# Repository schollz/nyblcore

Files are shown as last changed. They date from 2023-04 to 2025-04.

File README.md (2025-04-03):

# nyblcore



## diy

- [Website](https://nyblcore.com)
- [Schematic](https://github.com/schollz/nyblcore/blob/main/board/schematic_v1.pdf)
- [Board files](https://github.com/schollz/nyblcore/tree/main/board)
- [Source code](https://github.com/schollz/nyblcore/blob/main/nyblcore/nyblcore.ino)
- [Firmware](https://infinitedigits.co/wares/nyblcore/#upload)
- [Instructions for uploading firmware](https://infinitedigits.co/wares/nyblcore/#uploading-firmware-tools) 
- [Video demonstration](https://www.youtube.com/watch?v=cA8lai6gwKw)
- [Video DIY guide](https://www.youtube.com/watch?v=mrZleTfIKjE)

## what is it?

nyblcore is...

- a tiny **ATtiny85-based sample player** device for diy enthusiasts.
- powered by a single AAA for **~5-8 hours of battery life**.
- holding 8 kB of storage for up to **1.2 seconds of 8-bit audio sampled @ 4.1 kHz**.
- controlled by multi-functional knobs that modulate tempo, volume, distortion.
- probability-based. knobs also control the chaos of **jump, retrig, stutter and stretch** fx.
- able to **load custom firmware / audio** using an [Arduino](https://www.amazon.com/Arduino-A000066-ARDUINO-UNO-R3/dp/B008GRTSV6/?tag=scholl-20&th=1) or an [AVR usb programmer](https://www.amazon.com/whiteeeen-Tiny-AVR-Programmer/dp/B09921SC7Z/?tag=scholl-20&th=1) with [web-based tool](https://www.notion.so/pikocore-desktop-adf8f2e380b94334857e884fe1b85dcd).
- entirely [open-source](https://github.com/schollz/nyblcore), wonderfully hackable.

nyblcore is available for purchase. The assembled version is ready to play, handmade by me. The kit version comes with all the components (battery included!) and instructions on how to solder it together. 

more information at the website: [nyblcore.com](https://nyblcore.com).

## support open-source

nyblcore is open-source, all the code and boards are on my github here. 

If you make this device yourself, please consider [sponsoring me on github](https://github.com/sponsors/schollz) to support my time and effort in this project and to continue to allow me to explore making devices and releasing them as open-source. 

of course, you can also support this work by [buying the device directly from me](https://nyblcore.com/#buy).

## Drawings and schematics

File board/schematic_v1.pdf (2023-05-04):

## ATTiny85

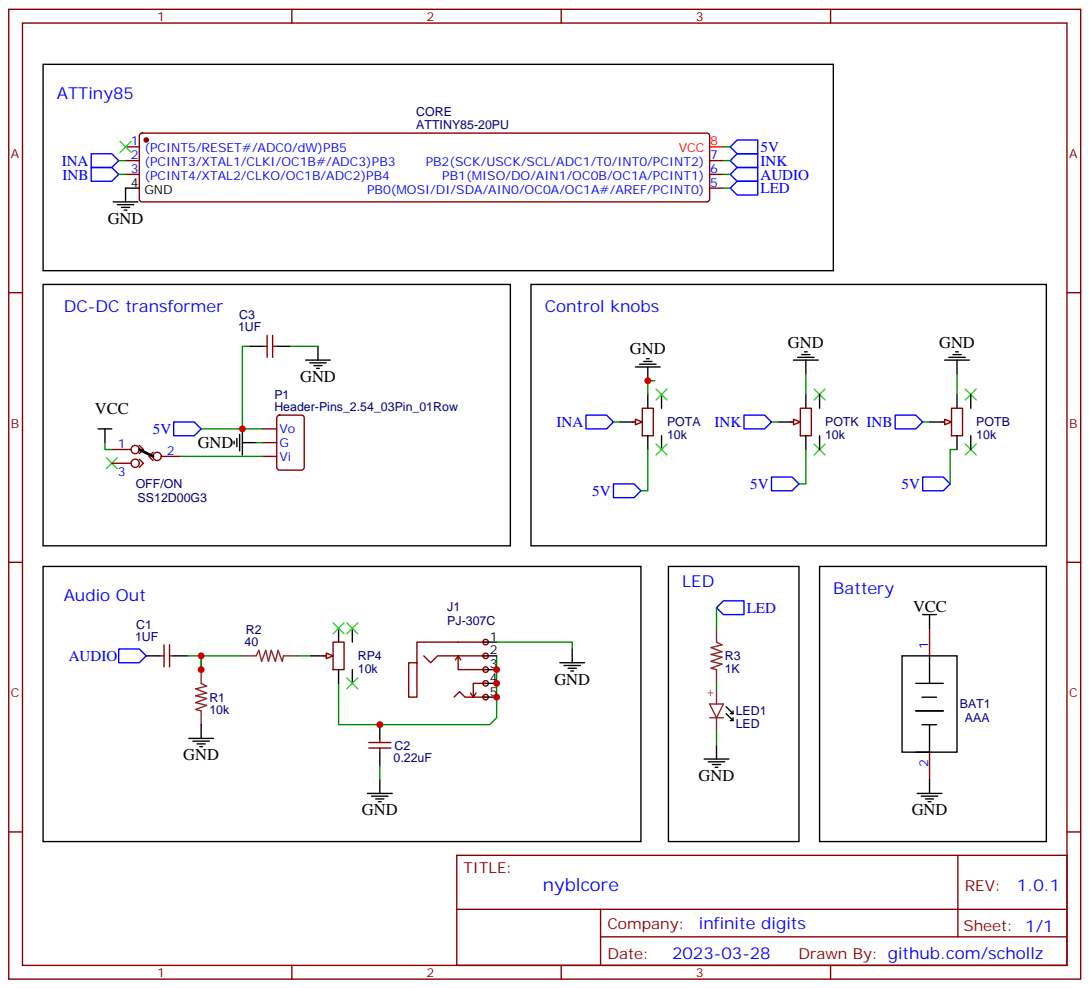
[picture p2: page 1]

PB0(MOSI/DI/SDA/AIN0/OC0A/OC1A#/AREF/PCINT0) 5

Drawn By: github.com/schollz

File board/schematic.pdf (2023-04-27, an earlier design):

## ATTiny85

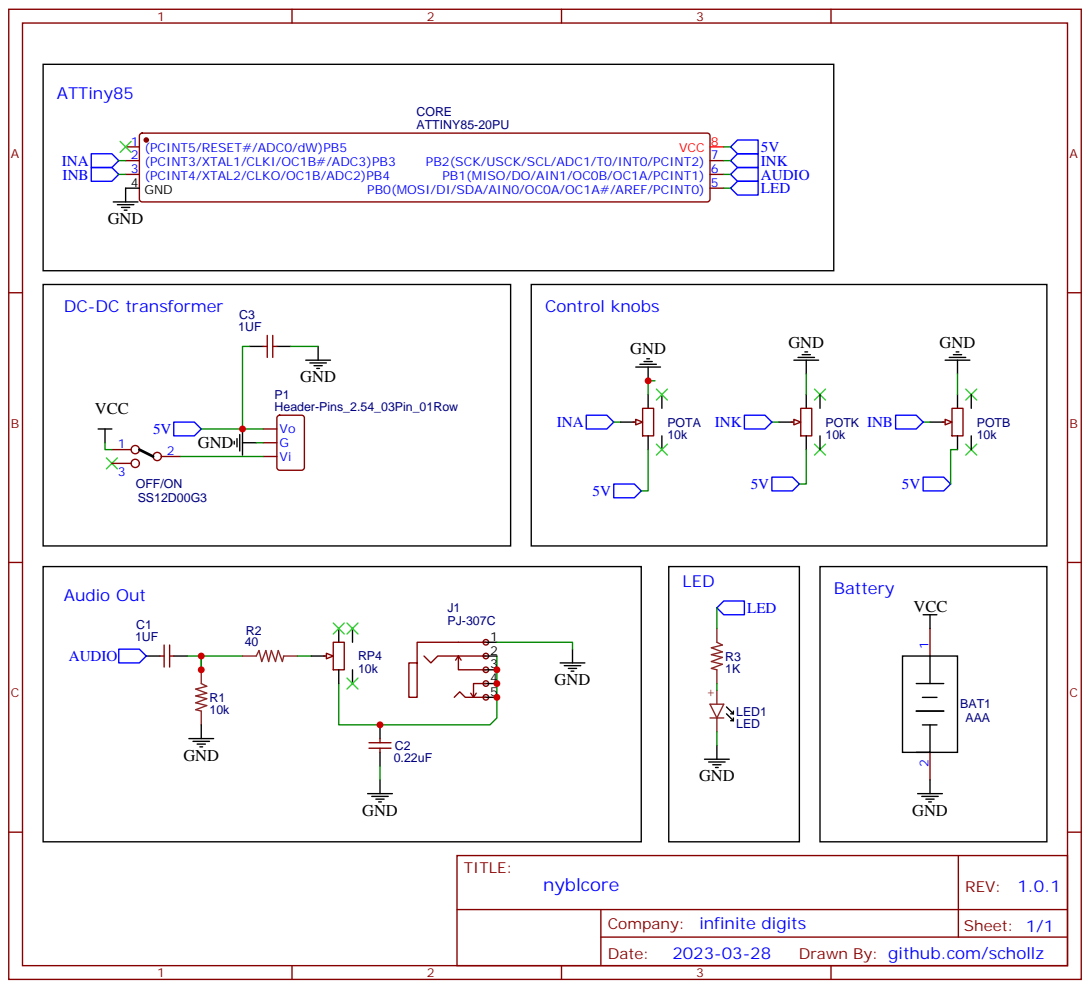
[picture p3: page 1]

PB0(MOSI/DI/SDA/AIN0/OC0A/OC1A#/AREF/PCINT0) 5

Drawn By: github.com/schollz

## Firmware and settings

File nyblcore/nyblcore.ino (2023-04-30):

// nyblcore v1.0.0
//
// ATtiny85 pinout:
//
//         +--u--+
//      NC |1   8| VCC
//     InA |2   7| InK
//     InB |3   6| Audio out
//     GND |4   5| LED out
//         +-----+
//

// <sample>
// SAMPLETABLE
// </sample>

#include <avr/eeprom.h>

// THE FOLLOWING 308 LINES OF CODE FOLLOWS THE MIT LICENSE
//
// MIT License
//
// Copyright (c) 2019 Strick Yak
//
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
#ifndef WHICH_PWM
#define WHICH_PWM 1 /* 1 or 4 */
#endif

#ifndef WHICH_LED
#define WHICH_LED 0
#endif

extern void Setup(void);
extern void Loop(void);

namespace nyblcore_internal {

// Timer/Counter 1 PWM Output OC1A (PB1)
struct FastPwm1Base {
  static void SetupPLL() {
    // de https://github.com/viking/attiny85-player //
    PLLCSR |= _BV(PLLE);  // Enable 64 MHz PLL (p94)
    // SpinDelay(1);         /// delayMicroseconds(100);            // Stabilize
    byte spin_tmp = 0;
    for (byte j = 0; j < 100; j++) {
      spin_tmp++;
    }
    while (!(PLLCSR & _BV(PLOCK)))
      ;                   // Wait for it... (p94)
    PLLCSR |= _BV(PCKE);  // Timer1 source = PLL
  };
};
struct FastPwm1A : public FastPwm1Base {
  static void Setup() {
    SetupPLL();

    // Set up Timer/Counter1 for PWM output
    TIMSK = 0;             // Timer interrupts OFF (p92)
    TCCR1 = _BV(PWM1A)     // Pulse Width Modulator A Enable. (p89)
            | _BV(COM1A1)  // Clear OC1A on match; set on count $00.
            | _BV(CS10);   // 1:1 prescale (p89)
    GTCCR = 0;             // Do not enable PW Modulater B. (p90)
    OCR1C = 255;           // Full 8-bit PWM cycle (p92)
    OCR1B = 0;             // Not used.
    OCR1A = 128;           // 50% duty at start

    pinMode(1, OUTPUT);  // Enable PWM output OC1A on pin PB1.
  }
  static void Output(int x) {
    OCR1A = x;  // (p92)
  }
};

struct FastPwm1B : public FastPwm1Base {
  static void Setup() {
    SetupPLL();

    // Set up Timer/Counter1 for PWM output
    TIMSK = 0;              // Timer interrupts OFF (p92)
    GTCCR = _BV(PWM1B)      // Pulse Width Modulator B Enable. (p89)
            | _BV(COM1B1);  // Clear OC1B on match; set on count $00 (p86).
    TCCR1 = _BV(CS10);      // Do not enable PW Modulater A. 1:1 prescale. (p89)
    OCR1C = 255;            // Full 8-bit PWM cycle (p92)
    OCR1A = 128;            // Not used.
    OCR1B = 128;            // 50% duty at start

    pinMode(4, OUTPUT);  // Enable PWM output OC1B on pin PB4.
  }
  static void Output(int x) {
    OCR1B = x;  // (p92)
  }
};

struct AnalogIn {
  static void NextInputA() {
    ADMUX = 0 |           // Use Vcc for Reference; disconnect from PB0 (p134)
            _BV(ADLAR) |  // Left-Adjust the ADC Result in ADCH (p134)
            3;            // ADC3 is PB3 is A.
  }
  static void NextInputB() {
    ADMUX = 0 |           // Use Vcc for Reference; disconnect from PB0 (p134)
            _BV(ADLAR) |  // Left-Adjust the ADC Result in ADCH (p134)
            2;            // ADC2 is PB4 is B.
  }
  static void NextInputK() {
    ADMUX = 0 |           // Use Vcc for Reference; disconnect from PB0 (p134)
            _BV(ADLAR) |  // Left-Adjust the ADC Result in ADCH (p134)
            1;            // ADC1 is PB2 is K.
  }
  static void Setup() {
    ADCSRA = _BV(ADEN);  // Enable ADC first.

    NextInputA();

    ADCSRB = 0;  // free-running ADC; not Bipolar; not reversed. (p137)

    // (p125) max ADC res: clock 50kHz to 200kHz
    // If less than 10 bits, 200khz to 1MHz.
    // We use internal 16MHz clock, so try dividing by 32.
    // 1->/2 2->/4 3->/8 4->/16 5->/32 6->/64 7->/128  (p136)
    // 7->4.88kHz   6->9.75kHz  5->19.53kHz Nyquist (freq of LED 2xToggle)
    // Use 6:   16MHz / 64 => 250kHz.
    // 250kHz / 13 => 19,230 samples per sec; nyquist 9615 Hz
    // Use 5: Can do two samples, 9615 Hz.
#define DIVISOR 5
    byte tmp = _BV(ADEN) |   // Enable the Analog-to-Digital converter (p136)
               _BV(ADATE) |  // Enable ADC auto trigger
               _BV(ADIE) |   // Enable interrupt on Conversion Complete
               DIVISOR;
    // ADCSRA = tmp;
    ADCSRA = tmp | _BV(ADSC);  // Start the fist conversion
  }
  static byte Input() {
    return ADCH;  // Just 8-bit.  Assumes ADLAR is 1.
  }
};

#if WHICH_PWM == 1
FastPwm1A pwm;
#else
FastPwm1B pwm;
#endif

volatile byte AnalogA, AnalogB, AnalogK;
AnalogIn in;
volatile byte adc_counter;
volatile bool adc_switch;

ISR(ADC_vect) {
  if (adc_switch) {
    ++adc_counter;
    adc_switch = false;
    // One time out of 256 we sample K.  The rest we sample B.
    if (adc_counter == 2) {
      AnalogB = ADCH;  // on 2, we still save B, but request K next.
      AnalogIn::NextInputK();
    } else if (adc_counter == 3) {
      AnalogK = ADCH;  // on 3, we save K, but request B again.
      AnalogIn::NextInputB();
    } else {
      AnalogB = ADCH;
      AnalogIn::NextInputB();
    }
  } else {
    adc_switch = true;
    AnalogA = ADCH;
    AnalogIn::NextInputA();
  }
}

void setup() {
  pinMode(0, INPUT_PULLUP);
  pinMode(1, INPUT_PULLUP);
  pinMode(2, INPUT_PULLUP);
  pinMode(3, INPUT_PULLUP);
  pinMode(4, INPUT_PULLUP);
  pinMode(5, INPUT_PULLUP);
  pinMode(WHICH_LED, OUTPUT);
  pinMode(WHICH_PWM, OUTPUT);

  pwm.Setup();
  in.Setup();

  ::Setup();  // Call user's Setup.
}

void loop() {
  // no need to return; just loop here.

  while (true) {
    // Wait for the next Analog sample in.
    {
      byte old_counter = adc_counter;
      byte c;
      do {
        c = adc_counter;
      } while (old_counter == c);
      if (byte(old_counter + 1) == c) {
      } else {
        // Fault on overruns.  ignore
      }
      old_counter = c;
    }

    ::Loop();  // Call user's Loop.
  }
}

}  // namespace nyblcore_internal

void setup() { nyblcore_internal::setup(); }
void loop() { nyblcore_internal::loop(); }

// public wrappers
inline byte InA() { return nyblcore_internal::AnalogA; }
inline byte InB() { return nyblcore_internal::AnalogB; }
inline byte InR() {
  return nyblcore_internal::AnalogK;
}  // R was old name for K.
inline byte InK() { return nyblcore_internal::AnalogK; }
inline void OutF(byte b) { nyblcore_internal::pwm.Output(b); }

#define IN_A() (nyblcore_internal::AnalogA)
#define IN_B() (nyblcore_internal::AnalogB)
#define IN_R() (nyblcore_internal::AnalogK)  // R was old name for K.
#define IN_K() (nyblcore_internal::AnalogK)
#define OUT_F(B) (nyblcore_internal::pwm.Output(B))

// using nyblcore_internal::SpinDelay;
// using nyblcore_internal::SpinDelayFast;

namespace nyblcore_random {

typedef struct rc4_key {
  unsigned char state[256];
  unsigned char x;
  unsigned char y;
} rc4_key;

void swap_byte(unsigned char *a, unsigned char *b) {
  unsigned char swapByte;

  swapByte = *a;
  *a = *b;
  *b = swapByte;
}

void prepare_key(unsigned char *key_data_ptr, int key_data_len, rc4_key *key) {
  unsigned char swapByte;
  unsigned char index1;
  unsigned char index2;
  unsigned char *state;
  short counter;

  state = &key->state[0];
  for (counter = 0; counter < 256; counter++) state[counter] = counter;
  key->x = 0;
  key->y = 0;
  index1 = 0;
  index2 = 0;
  for (counter = 0; counter < 256; counter++) {
    index2 = (key_data_ptr[index1] + state[counter] + index2) % 256;
    swap_byte(&state[counter], &state[index2]);

    index1 = (index1 + 1) % key_data_len;
  }
}

void rc4(unsigned char *buffer_ptr, int buffer_len, rc4_key *key) {
  unsigned char x;
  unsigned char y;
  unsigned char *state;
  unsigned char xorIndex;
  short counter;

  x = key->x;
  y = key->y;

  state = &key->state[0];
  for (counter = 0; counter < buffer_len; counter++) {
    x = (x + 1) % 256;
    y = (state[x] + y) % 256;
    swap_byte(&state[x], &state[y]);

    xorIndex = state[x] + (state[y]) % 256;

    buffer_ptr[counter] ^= state[xorIndex];
  }
  key->x = x;
  key->y = y;
}

rc4_key Engine;

}  // namespace nyblcore_random

void RandomSetup() {
  nyblcore_random::prepare_key("RandomSetup", 12, &nyblcore_random::Engine);
}

byte RandomByte() {
  unsigned char buf[1] = {0};
  nyblcore_random::rc4(buf, 1, &nyblcore_random::Engine);
  return buf[0];
}

//
// THE PREVIOUS CODE FOLLOWS THE MIT LICENSE
//

#define SHIFTY 6
#define PARM1 30
#define PARM2 220

byte distortion = 0;
byte volume_reduce = 0;  // volume 0 to 6
byte volume_mod = 0;
byte thresh_counter = 0;
byte thresh_next = 3;
bool thresh_nibble = 0;
word phase_sample = 0;
word phase_sample_last = 11;
byte thresh_counter_t = 0;
byte thresh_next_t = 3;
bool thresh_nibble_t = 0;
word phase_t = 0;
byte select_sample = 0;
byte select_sample_start = 0;
byte select_sample_end = NUM_SAMPLES - 1;
bool direction = 1;  // 0 = reverse, 1 = forward
byte retrig = 4;
byte tempo = 12;
int audio_last = 0;
int audio_next = -1;
byte audio_now = 0;
byte audio_played = 0;
char audio_add = 0;
char stretch_amt = 0;
word stretch_add = 0;
byte knobB_last = 0;
byte knobA_last = 0;
byte knobK_last = 0;
byte probability = 0;
bool do_retrigger = false;
bool do_stutter = false;
bool do_stretch = false;
bool do_stretch_slow = true;
byte do_retriggerp = false;
byte do_stutterp = false;
byte do_stretchp = false;
byte bcount = 0;
byte lastMoved = 0;
bool firstrun = true;
word debounce_eeprom = 0;

#define NUM_TEMPOS 19
const byte tempo_steps[] = {0xAA, 0xA9, 0x99, 0x98, 0x88, 0x87, 0x77,
                            0x76, 0x66, 0x65, 0x55, 0x54, 0x44, 0x43,
                            0x33, 0x32, 0x22, 0x21, 0x11};

void Setup() { RandomSetup(); }

void Loop() {
  byte knobA = InA();
  byte knobK = InK();
  byte knobB = InB();
  if (firstrun) {
    firstrun = false;
    if (eeprom_read_byte((uint8_t *)1) == 18) {
      tempo = eeprom_read_byte((uint8_t *)0);
      if (tempo > NUM_TEMPOS) tempo = 13;
      volume_reduce = eeprom_read_byte((uint8_t *)2);
      if (volume_reduce > 10) volume_reduce = 0;
      distortion = eeprom_read_byte((uint8_t *)3);
      if (distortion > 55) distortion = 0;
      probability = eeprom_read_byte((uint8_t *)4);
      if (probability > 128) probability = 0;
      do_stretchp = eeprom_read_byte((uint8_t *)5);
      if (do_stretchp > 128) do_stretchp = 0;
      do_retriggerp = eeprom_read_byte((uint8_t *)6);
      if (do_retriggerp > 63) do_retriggerp = 0;
      do_stutterp = eeprom_read_byte((uint8_t *)7);
      if (do_stutterp > 63) do_stutterp = 0;
    } else {
      eeprom_write_byte((uint8_t *)1, 18);
    }
    knobA_last = knobA;
    knobK_last = knobK;
    knobB_last = knobB;
  } else if (debounce_eeprom > 0) {
    debounce_eeprom--;
    if (debounce_eeprom == 0) {
      eeprom_write_byte((uint8_t *)0, tempo);
      eeprom_write_byte((uint8_t *)2, volume_reduce);
      eeprom_write_byte((uint8_t *)3, distortion);
      eeprom_write_byte((uint8_t *)4, probability);
      eeprom_write_byte((uint8_t *)5, do_stretchp);
      eeprom_write_byte((uint8_t *)6, do_retriggerp);
      eeprom_write_byte((uint8_t *)7, do_stutterp);
    }
  }
  bcount++;
  byte bthresh = knobA;
  if (lastMoved == 1) {
    bthresh = knobK;
  } else if (lastMoved == 2) {
    bthresh = knobB;
  }
  if (bcount < bthresh) {
    digitalWrite(WHICH_LED, HIGH);
  } else {
    digitalWrite(WHICH_LED, LOW);
  }
  if (bcount == 255) {
    bcount = 0;
  }

  if (phase_sample_last != phase_sample) {
    audio_last = ((int)pgm_read_byte(SAMPLE_TABLE + phase_sample)) << SHIFTY;
    if (thresh_next > thresh_counter) {
      audio_next = ((int)pgm_read_byte(SAMPLE_TABLE + phase_sample +
                                       (direction * 2 - 1)))
                   << SHIFTY;
      audio_next =
          (audio_next - audio_last) / ((int)(thresh_next - thresh_counter));
    } else {
      audio_next = 0;
    }
    audio_add = 0;
    phase_sample_last = phase_sample;
  }
  // no interpolation
  // OutF(audio_last >> SHIFTY);

  if (knobK > knobK_last + 5 || knobK < knobK_last - 5) {
    lastMoved = 1;
    knobK_last = knobK;
  }
  if (knobA > knobA_last + 5 || knobA < knobA_last - 5) {
    lastMoved = 0;
    knobA_last = knobA;
    // update the left parameter
    if (knobK < PARM1) {
      // volume
      if (knobA <= 200) {
        volume_reduce = (200 - knobA) * 10 / 200;  // 0-220 -> 10-0
        distortion = 0;
      } else {
        volume_reduce = 0;
        distortion = knobA - 200;  // 200-255 -> 0-55
      }
    } else if (knobK < PARM2) {
      probability = knobA / 2;  // 0-255 -> 0-100
    } else {
      do_stretchp = knobA / 2;
    }
    debounce_eeprom = 65534;
  }
  if (knobB > knobB_last + 5 || knobB < knobB_last - 5) {
    lastMoved = 2;
    knobB_last = knobB;
    // update the right parameter
    if (knobK < PARM1) {
      tempo = knobB * NUM_TEMPOS / 255;
    } else if (knobK < PARM2) {
      do_retriggerp = knobB / 4;
    } else {
      do_stutterp = knobB / 4;
    }
    debounce_eeprom = 65534;
  }

  // linear interpolation with shifts
  audio_now = (audio_last + audio_add) >> SHIFTY;

  // mute audio if volume_reduce==10
  if (volume_reduce == 10) audio_now = 128;

  // if not muted, make some actions
  if (audio_now != 128) {
    // distortion / wave-folding
    if (distortion > 0) {
      if (audio_now > 128) {
        if (audio_now < (255 - distortion)) {
          audio_now += distortion;
        } else {
          audio_now = 255 - distortion;
        }
        // too much cpu
        // audio_now = 128 + ((audio_now - 128) / ((distortion >> 4) + 1));
      } else {
        if (audio_now > distortion) {
          audio_now -= distortion;
        } else {
          audio_now = distortion - audio_now;
        }
        // too much cpu
        // audio_now = 128 - ((128 - audio_now) / ((distortion >> 4) + 1));
      }
    }
    // reduce volume
    if ((volume_reduce + volume_mod) > 0) {
      if (audio_now > 128) {
        audio_now = ((audio_now - 128) >> (volume_reduce + volume_mod)) + 128;
      } else {
        audio_now = 128 - ((128 - audio_now) >> (volume_reduce + volume_mod));
      }
    }
  }
  // click preventer??
  if (abs(audio_now - audio_played) > 32) {
    audio_now = (audio_now + audio_played) / 2;
    if (abs(audio_now - audio_played) > 32) {
      audio_now = (audio_now + audio_played) / 2;
    }
  }
  OutF(audio_now);
  audio_played = audio_now;
  // for linear interpolation
  audio_add = audio_add + audio_next;

  // audio sample iterations
  thresh_counter++;
  if (thresh_counter == thresh_next) {
    thresh_counter = 0;
    thresh_nibble = 1 - thresh_nibble;
    thresh_next = tempo_steps[tempo - stretch_amt];
    if (thresh_nibble) {
      thresh_next = (byte)(thresh_next & 0xF0) >> 4;
    } else {
      thresh_next = (byte)(thresh_next & 0x0F);
    }

    // determine directions
    if (direction) {
      // forward
      if (phase_sample < pos[NUM_SAMPLES]) {
        phase_sample++;
      } else {
        phase_sample = 0;
      }
    } else {
      // reverse
      if (phase_sample == 0) {
        phase_sample = pos[NUM_SAMPLES];
      } else {
        phase_sample--;
      }
    }
  }

  // tempo clocked effects
  thresh_counter_t++;
  if (thresh_counter_t == thresh_next_t) {
    thresh_counter_t = 0;
    thresh_nibble_t = 1 - thresh_nibble_t;
    thresh_next_t = tempo_steps[tempo];
    if (thresh_nibble_t) {
      thresh_next_t = (byte)(thresh_next_t & 0xF0) >> 4;
    } else {
      thresh_next_t = (byte)(thresh_next_t & 0x0F);
    }

    phase_t++;
    if (phase_t == retrigs[retrig]) {
      phase_t = 0;
      // randoms
      byte r1 = RandomByte();
      byte r2 = RandomByte();
      byte r3 = RandomByte();
      byte r4 = RandomByte();

      if (select_sample == 0) {
        do_stretch_slow = r1 < 200;
      }
      // do stretching
      if (do_stretchp > 10) {
        do_stretch = (r1 < do_stretchp);
      } else {
        do_stretch = false;
      }
      if (do_stretch) {
        if (do_stretch_slow) {
          stretch_amt++;
        } else {
          stretch_amt--;
        }
        if (tempo - 1 < stretch_amt) {
          stretch_amt = tempo - 1;
        } else if (tempo - NUM_TEMPOS + 1 > stretch_amt) {
          stretch_amt = tempo - NUM_TEMPOS + 1;
        }
      } else {
        stretch_amt = 0;
      }

      if (volume_mod > 0) {
        if (volume_mod > 3 || r3 < 200) {
          volume_mod--;
        }
      } else {
        // randomize direction
        if (direction == 1) {
          if (r1 < probability / 4) {
            direction = 0;
          }
        } else {
          if (r1 < probability || probability < 10) {
            direction = 1;
          }
        }

        // random retrig
        if (r2 < probability / 4) {
          retrig = 6;
        } else if (r2 < probability / 3) {
          retrig = 5;
        } else if (r2 < probability / 2) {
          retrig = 3;
        } else if (r2 < probability) {
          retrig = 2;
        } else {
          retrig = 4;
        }

        if (do_retrigger == false && do_stutter == false) {
          // select new sample based on direction
          if (direction == 1) select_sample++;
          if (direction == 0) {
            if (select_sample == 0) {
              select_sample = select_sample_end;
            } else {
              select_sample--;
            }
          }

          // make sure the new sample is not out of bounds
          if (select_sample < select_sample_start)
            select_sample = select_sample_end;
          if (select_sample > select_sample_end)
            select_sample = select_sample_start;

          // random jump
          if (r3 < probability / 2) {
            // thresh_next = thresh_next + (r1 * 4 / 255);
            // retrig = (RandomByte() * 6 / 255);
            select_sample = (RandomByte() * NUM_SAMPLES) / 255;
          }
        }

        if (do_retriggerp > 10) {
          do_retrigger = (r4 < do_retriggerp);
        } else {
          do_retrigger = false;
        }
        if (do_retrigger) {
          retrig = 6;
          if (r2 < 120) {
            retrig = 5;
          }
        }

        if (do_stutterp > 10) {
          do_stutter = (r3 < do_stutterp);
        } else {
          do_stutter = false;
        }
        if (do_stutter) {
          if (volume_mod == 0) {
            volume_mod = r2 * 6 / 255;
            if (r3 < 120) {
              retrig = 5;
            } else {
              retrig = 6;
            }
          }
        }
      }
      phase_sample = pos[select_sample];
    }
  }
}

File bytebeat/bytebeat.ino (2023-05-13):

// nyblcore v0.5 generated 2023-05-13 09:32:08.324841391 +0000 UTC
// m=+241366.089201989 drum.wav 5 slices

// nyblcore v1.0.0
//
// ATtiny85 pinout:
//
//         +--u--+
//      NC |1   8| VCC
//     InA |2   7| InK
//     InB |3   6| Audio out
//     GND |4   5| LED out
//         +-----+
//

// #include <avr/eeprom.h>

// THE FOLLOWING 308 LINES OF CODE FOLLOWS THE MIT LICENSE
//
// MIT License
//
// Copyright (c) 2019 Strick Yak
//
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
unsigned long t = 0;

// <bb>
// {"description": "frequency dancer", "author": "ANON256-64", "url":
// "https://www.reddit.com/r/bytebeat/comments/11krrl8/frequency_dancer/",
// "date": "2023-03-07", "codeOriginal": "(t%125&t>>8)|t>>4|t*t>>8&t>>8",
// "codeMinified": "t%125&t>>8|t>>4|t*t>>8&t>>8"}
byte bb0_vals[] = {125, 8, 4, 8, 8};
byte bb0_set(byte a, byte b) { bb0_vals[a * 5 / 255] = b * 249 / 255; }
byte bb0() {
  return (t % bb0_vals[0] & t >> bb0_vals[1]) | t >> bb0_vals[2] |
         t * t >> bb0_vals[3] & t >> bb0_vals[4];
}
// {"author": "ryg", "children": [{"description": "triangle waves", "url":
// "http://www.pouet.net/topic.php?which=8357&page=11#c389010", "date":
// "2011-10-05", "codeOriginal": "(t<<5)^-(t>>3&1)"}, {"description": "the
// general form is (t<&lt;N)^-(t<<(N-8)&1)", "codeOriginal":
// "(t<<4)^-(t>>4&1)"}, {"codeOriginal": "(t<<3)^-(t>>5&1)"}, {"description": "a
// jaunty tune", "url":
// "http://www.pouet.net/topic.php?which=8357&page=17#c389829", "date":
// "2011-10-10", "codeOriginal":
// "(t*(t>>12)*64+(t>>1)*(t>>10)*(t>>11)*48)>>(((t>>16)|(t>>17))&1)",
// "codeMinified":
// "t*(t>>12)*64+(t>>1)*(t>>10)*(t>>11)*48>>((t>>16|t>>17)&1)"}]}
byte bb1_vals[] = {4, 4, 1};
byte bb1_set(byte a, byte b) { bb1_vals[a * 3 / 255] = b * 7 / 255; }
byte bb1() { return (t << bb1_vals[0]) ^ -(t >> bb1_vals[bb1_vals[2]] & 1); }
// {"author": "viznut", "children": [{"url":
// "http://viznut.fi/demos/unix/bytebeat_formulas.txt", "date": "2011-09-18",
// "codeOriginal": "t*(((t>>12)|(t>>8))&(63&(t>>4)))", "codeMinified":
// "t*((t>>12|t>>8)&63&t>>4)"}, {"description": "Sin() isn't kosher, people!",
// "url": "https://www.pouet.net/topic.php?which=8357&page=4#c388477", "date":
// "2011-09-30", "codeOriginal": "(t>>6|t|t>>(t>>16))*10+((t>>11)&7)",
// "codeMinified": "10*(t>>6|t|t>>(t>>16))+(7&t>>11)", "starred": 1},
// {"description": "Combined xpansive's and varjohukka's stuff", "url":
// "https://www.pouet.net/topic.php?which=8357&page=4#c388488", "date":
// "2011-09-30", "codeOriginal": "(t>>7|t|t>>6)*10+4*(t&t>>13|t>>6)", "starred":
// 2}, {"description": "Another attempt at melody construction (\"Running
// man\")", "url": "http://www.pouet.net/topic.php?which=8357&page=9#c388930",
// "date": "2011-10-04", "codeOriginal":
// "(t*((3+(1^t>>10&5))*(5+(3&t>>14))))>>(t>>8&3)", "codeMinified":
// "t*(3+(1^t>>10&5))*(5+(3&t>>14))>>(t>>8&3)", "starred": 2}, {"description":
// "#countercomplex \"moon scanner generalization\", based on jaffa's formula",
// "url": "http://viznut.fi/demos/unix/bytebeat_formulas.txt", "date":
// "2011-10-06", "codeOriginal": "((t>>5&t)-(t>>5)+(t>>5&t))+(t*((t>>14)&14))",
// "codeMinified": "2*(t>>5&t)-(t>>5)+t*(t>>14&14)", "starred": 1}]}
byte bb2_vals[] = {7, 6, 10, 4, 13, 6};
byte bb2_set(byte a, byte b) { bb2_vals[a * 6 / 255] = b * 25 / 255; }
byte bb2() {
  return (t >> bb2_vals[0] | t | t >> bb2_vals[1]) * bb2_vals[2] +
         bb2_vals[3] * (t & t >> bb2_vals[4] | t >> bb2_vals[5]);
}
// {"author": "GDPlayer_1035", "children": [{"description": "test3", "url":
// "https://www.reddit.com/r/bytebeat/comments/q6ar3c/test3/", "date":
// "2021-10-12", "sampleRate": 44100, "codeOriginal":
// "((t*t-t/400*t/800^t/900)&192&-t/30)+t/40&t/80^t/80"}, {"description":
// "thing", "url": "https://www.reddit.com/r/bytebeat/comments/q8cqdv/thing/",
// "date": "2021-10-15", "sampleRate": 44100, "codeOriginal":
// "(t&t/2&t/4)*t/4E3", "starred": 1}]}
byte bb3_vals[] = {2, 4};
byte bb3_set(byte a, byte b) { bb3_vals[a * 2 / 255] = b * 7 / 255; }
byte bb3() { return (t & t / bb3_vals[0] & t / bb3_vals[1]) * t / 4E3; }
// {"author": "Unknown", "url":
// "https://www.reddit.com/r/bytebeat/comments/20km9l/cool_equations/", "date":
// "2014-03-16", "children": [{"description": "Wip", "codeOriginal":
// "(((t&t*5)|t>>4)+(t|t>>4*t<<8-1))^t>>12", "codeMinified":
// "(t&5*t|t>>4)+(t|t>>4*t<<7)^t>>12"}, {"description": "Extremely loud grinding
// machine", "codeOriginal": "t/(t%(t>>8|t>>16))", "starred": 1},
// {"description": "Everything is broken", "codeOriginal":
// "(t*t/(1+(t>>9&t>>8)))&128", "codeMinified": "t*t/(1+(t>>9&t>>8))&128",
// "starred": 1}, {"description": "It wont stop", "codeOriginal":
// "t*((t/401)^(t/400))", "codeMinified": "t*(t/401^t/400)"}, {"description":
// "Ststututterter", "codeOriginal": "(t*(-(t>>8|t|t>>9|t>>13)))^t",
// "codeMinified": "t*-(t>>8|t|t>>9|t>>13)^t"}, {"description": "Waiver",
// "codeOriginal": "(((t/91)&t)^((t/90)&t))-1", "codeMinified":
// "(t/91&t^t/90&t)-1"}, {"description": "Glissando", "codeOriginal":
// "(t*t)/(t>>13 ^ t>>8)", "codeMinified": "t*t/(t>>13^t>>8)"}, {"description":
// "Plucker v2", "codeOriginal": "((t/4)>>t/4)|(t>>2)", "codeMinified":
// "t/4>>t/4|t>>2"}]}
byte bb4_vals[] = {8, 9, 13};
byte bb4_set(byte a, byte b) { bb4_vals[a * 3 / 255] = b * 25 / 255; }
byte bb4() {
  return (t * (-(t >> bb4_vals[0] | t | t >> bb4_vals[1] | t >> bb4_vals[2]))) ^
         t;
}
// {"author": "xpansive", "children": [{"description": "Lost in Space", "url":
// "http://www.pouet.net/topic.php?which=8357&page=3#c388375", "date":
// "2011-09-29", "codeOriginal": "((t*(t>>8|t>>9)&46&t>>8)) ^ (t&t>>13|t>>6)",
// "codeMinified": "t*(t>>8|t>>9)&46&t>>8^(t&t>>13|t>>6)"}, {"url":
// "http://www.pouet.net/topic.php?which=8357&page=21#c401775", "date":
// "2012-02-25", "codeOriginal": "t%(t/(t>>9|t>>13))"}]}
byte bb5_vals[] = {8, 9, 46, 8, 13, 6};
byte bb5_set(byte a, byte b) { bb5_vals[a * 6 / 255] = b * 91 / 255; }
byte bb5() {
  return ((t * (t >> bb5_vals[0] | t >> bb5_vals[1]) & bb5_vals[2] &
           t >> bb5_vals[3])) ^
         (t & t >> bb5_vals[4] | t >> bb5_vals[5]);
}
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

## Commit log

2023-04-23 don't let get stuck backwards
    [nyblcore.ino]
2023-04-27 add board info
    [Drill_NPTH_Through.DRL, Drill_PTH_Through.DRL, Drill_PTH_Through_Via.DRL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]
2023-04-30 increase sample rate
2023-05-04 add board
    [Drill_NPTH_Through.DRL, Drill_PTH_Through.DRL, Drill_PTH_Through_Via.DRL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]
